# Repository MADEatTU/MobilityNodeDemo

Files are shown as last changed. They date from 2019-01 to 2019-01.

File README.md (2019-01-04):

# Mobility Node Demo
Proof of concept for CAN-bus connected mobility project modules.

This is a minimally viable circuit to prototype firmware and electrical designs communicating over CAN bus. Each board has one LED and three push buttons, allowing both targeted and global message passing to be tested. Boards are capable of daisy-chaining.

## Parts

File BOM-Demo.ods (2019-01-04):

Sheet: Timer
 | Description | Schematic Number | Manufacturer | Unit Price | Part # | Quantity | Total | Package | Link
1 | Arduino Nano | A1 |  | $4.62 |  | 1 | $4.62 |  | https://www.amazon.com/ELEGOO-Arduino-ATmega328P-Without-Compatible/dp/B0713XK923
2 | 1 uF Capacitor | C1 | Wurth | $0.15 | 710-885012208036 | 1 | $0.15 | SMD 1206 | https://www.mouser.com/ProductDetail/Wurth-Electronics/885012208036
3 | 0.1 uF Capacitor | C2, C5 | AVX | $0.10 | 581-12101C104KAZ4A | 2 | $0.20 | SMD 1210 | https://www.mouser.com/ProductDetail/AVX/12101C104KAZ4A
4 | 22 pF Capacitor | C3, C4 | Wurth | $0.11 | 710-885012008011 | 2 | $0.22 | SMD 1206 | https://www.mouser.com/ProductDetail/Wurth-Electronics/885012008011
5 | Schottky Diode | D1 | Rectron | $0.10 | 583-FM5817 | 1 | $0.10 | DO-214AC | https://www.mouser.com/ProductDetail/Rectron/FM5817-W
6 | Zener Diode 12V | D2 | ON | $0.14 | 863-BZX84C13LT1G | 1 | $0.14 | SOT-23 | https://www.mouser.com/ProductDetail/ON-Semiconductor/BZX84C13LT1G
7 | RJ14 Port | J1 | Molex | $0.78 | 538-95009-7641 | 2 | $1.56 |  | https://www.mouser.com/ProductDetail/Molex/95009-7641
 | 6.8 Ohm Resistor | R1 | Vishay | $0.10 | 71-CRCW1206-6.04-E3 | 1 | $0.10 | SMD 1206 | https://www.mouser.com/ProductDetail/Vishay/CRCW12066R04FKEA
8 | 100 Ohm Resistor | R2 | Ohmite | $0.10 | 588-AS12J1000ET | 1 | $0.10 | SMD 1206 | https://www.mouser.com/ProductDetail/Ohmite/AS12J1000ET
9 | 1k Ohm Resistor | R3-R6 | Vishay | $0.10 | 71-CRCW12061K00JNEAC | 4 | $0.40 | SMD 1206 | https://www.mouser.com/ProductDetail/Vishay/CRCW12061K00JNEAC
10 | 22k Ohm Resistor | R4, R5 | Bourns | $0.10 | 652-CR1206JW-223ELF | 1 | $0.10 | SMD 1206 | https://www.mouser.com/ProductDetail/Bourns/CR1206-JW-223ELF?qs=sGAEpiMZZMu61qfTUdNhG6LqqFhkr6pUaJfsmI3sDEY%3d
11 | Push Button Switch | SW1 | E-Switch | $0.17 | 612-TS-7.0-100 | 3 | $0.51 |  | https://www.mouser.com/ProductDetail/E-Switch/TS-70-100
12 | CAN Bus Transciever | U1 | Microchip | $1.06 | 579-MCP2551-I/SN | 1 | $1.06 | SOIC-8 | https://www.mouser.com/ProductDetail/Microchip-Technology/MCP2551-I-SN?qs=sGAEpiMZZMsUzhEcHltCudXjf0%252bf93ff
13 | CAN Bus Controller | U2 | Microchip | $1.88 | 579-MCP2515-I/SO | 1 | $1.88 | SOIC-18 | https://www.mouser.com/ProductDetail/Microchip-Technology/MCP2515-I-SO?qs=sGAEpiMZZMsUzhEcHltCuTyUJ%252bMSzD1r
14 | 8MHz Crystal Oscilator | Y1 | IQD | $0.23 | 449-LFXTAL030234REEL | 1 | $0.23 | HC49S | https://www.mouser.com/ProductDetail/IQD/LFXTAL030234Reel
15 | 15 position female header |  | Gravitech | $1.05 | 992-15FX1-254MM | 2 | $2.10 | SIP-15 | https://www.mouser.com/ProductDetail/Gravitech/15Fx1-254mm
 |  |  |  |  |  | Total: | $11.37

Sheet: ORDER THESE
Part # | Quantity | Units: | 5
710-885012208036 | 5
581-12101C104KAZ4A | 10
710-885012008011 | 10
583-FM5817 | 5
863-BZX84C13LT1G | 5
538-95009-7641 | 10
71-CRCW1206-6.04-E3 | 5
588-AS12J1000ET | 5
71-CRCW12061K00JNEAC | 20
652-CR1206JW-223ELF | 10
612-TS-7.0-100 | 15
579-MCP2551-I/SN | 4
579-MCP2515-I/SO | 4
449-LFXTAL030234REEL | 4
992-15FX1-254MM | 6

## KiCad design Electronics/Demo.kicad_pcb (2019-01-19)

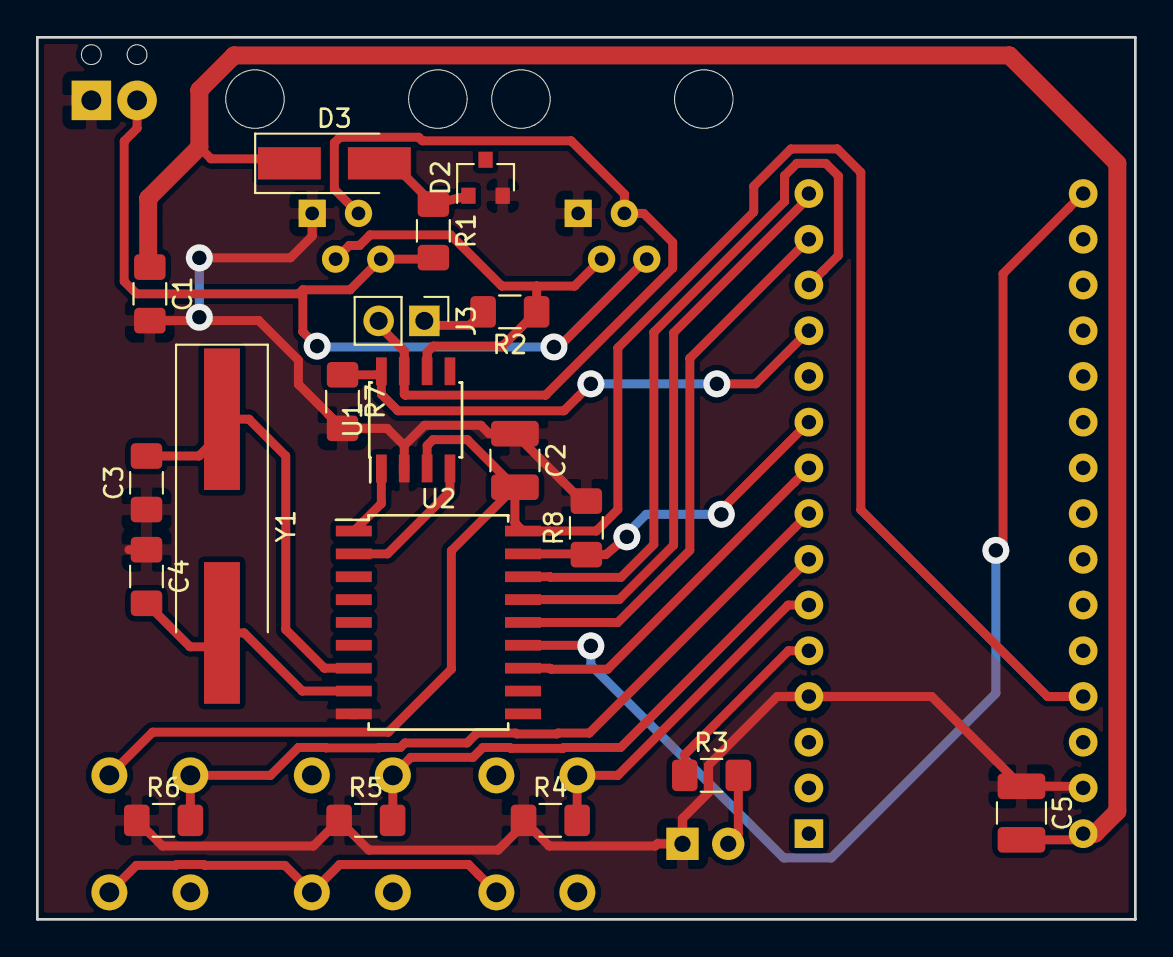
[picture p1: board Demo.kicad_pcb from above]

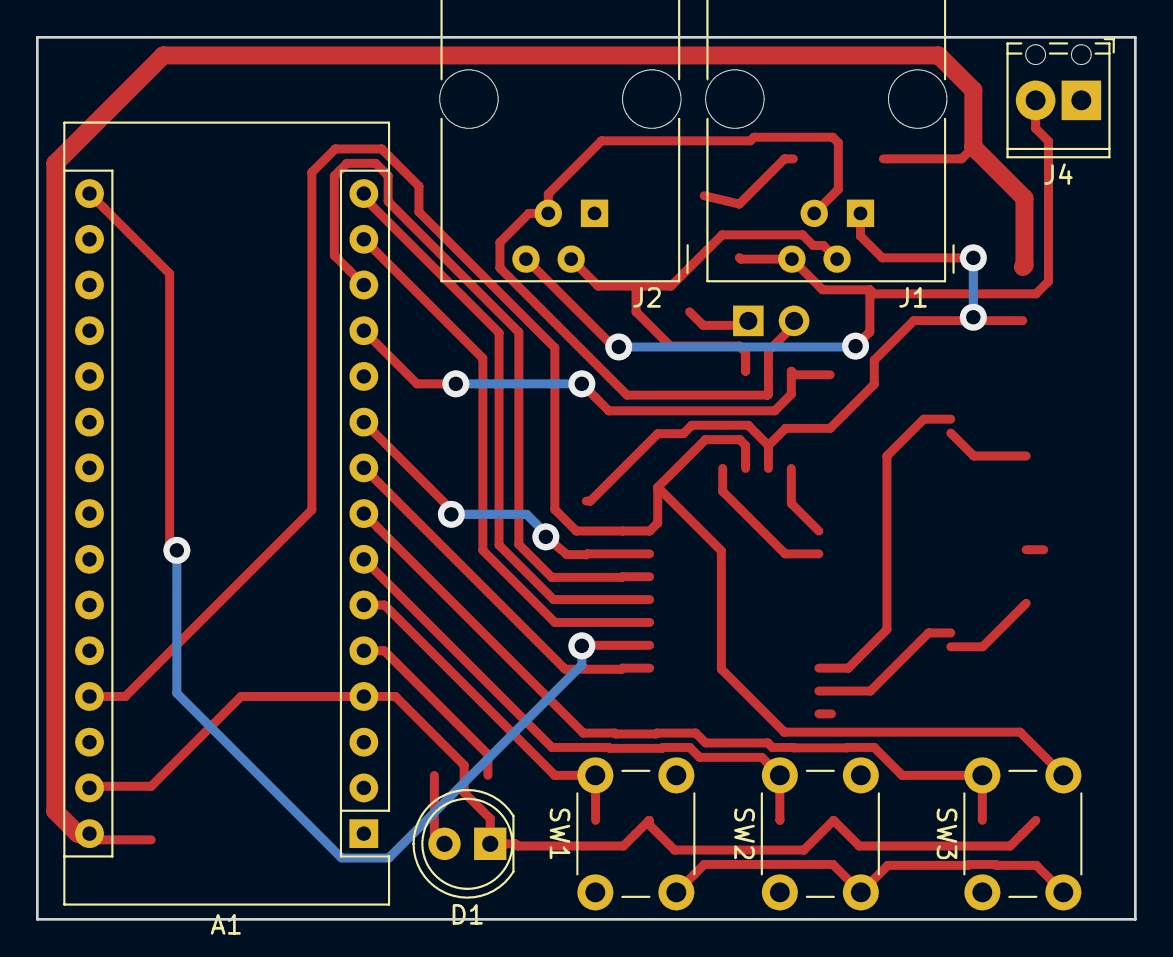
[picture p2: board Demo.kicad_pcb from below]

Board: 2 copper layers, 61.0 x 49.0 mm, 27 parts (8 on the bottom side), 24 nets.

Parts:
A1: Arduino_Nano_v3.x; Arduino_Nano
C1: 1uF; C_1206_3216Metric_Pad1.42x1.75mm_HandSolder
C2, C5: 0.1uF; C_1210_3225Metric_Pad1.42x2.65mm_HandSolder
C3, C4: 22pF; C_1206_3216Metric_Pad1.42x1.75mm_HandSolder
D1: LED; LED_D5.0mm
D2: 12V; SOT-23
D3: D_Schottky; D_SMA_Handsoldering
J1, J2: RJ10; RJ14
J3: Conn_01x02_Male; PinHeader_1x02_P2.54mm_Vertical
J4: PWR; TerminalBlock_Phoenix_MPT-0,5-2-2.54_1x02_P2.54mm_Horizontal
R1: 6.8; R_1206_3216Metric_Pad1.42x1.75mm_HandSolder
R2: 100; R_1206_3216Metric_Pad1.42x1.75mm_HandSolder
R3, R4, R5, R6: 1k; R_1206_3216Metric_Pad1.42x1.75mm_HandSolder
R7, R8: 22k; R_1206_3216Metric_Pad1.42x1.75mm_HandSolder
SW1, SW2, SW3: SW_Push; SW_PUSH_6mm_H4.3mm
U1: MCP2551-I-SN; SOIC-8_3.9x4.9mm_P1.27mm
U2: MCP2515-xSO; SOIC-18W_7.5x11.6mm_P1.27mm
Y1: 8MHz; Crystal_SMD_HC49-SD_HandSoldering

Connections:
+5V: A1.27, C2.2, SW1.2, SW2.2, SW3.2, U1.3, U2.18
+12V: A1.30, C1.1, C5.2, D3.1
/CANH: J1.3, J2.3, J3.2, U1.7
/CANL: J1.2, J2.2, R2.1, U1.6
/CAN_RST: A1.10, R8.1, U2.17
/CS: A1.13, U2.16
/LED: A1.5, R3.1
/RXD: U1.4, U2.2
/S1: A1.6, R4.2, SW1.1
/S2: A1.7, R5.2, SW2.1
/S3: A1.8, R6.2, SW3.1
/SCK: A1.16, U2.13
/SI: A1.14, U2.14
/SO: A1.15, U2.15
/TXD: U1.1, U2.1
/Vin: J1.4, J2.4, J4.2, R1.2
/XCDR_RST: A1.12, R7.1, U1.8
/int: A1.9, U2.12
GND: A1.4, A1.29, C1.2, C2.1, C3.1, C4.1, C5.1, D1.1, D2.2, J1.1, J2.1, J4.1, R4.1, R5.1, R6.1, R7.2, R8.2, U1.2, U2.9
unnamed: C3.2, U2.7, Y1.1
unnamed: C4.2, U2.8, Y1.2
unnamed: D1.2, R3.2
unnamed: D2.1, D3.2, R1.1
unnamed: J3.1, R2.2

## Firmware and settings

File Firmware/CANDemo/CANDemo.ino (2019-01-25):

#include <can.h>
#include <mcp2515.h>


void setup() {
  MCP2515 mcp2515(10);
  mcp2515.reset();
  mcp2515.setBitrate(CAN_125KBPS);
  mcp2515.setLoopbackMode();
  self.ID = 0;
}

void loop() {
  // put your main code here, to run repeatedly:
  // compare button state to previous
  // if button pressed == self.ID
    // set self.LED status == button status
  // else:
    // button_pressed(button_pressed, button_status)
  
  // on interupt: if can_id == self.ID:
    // set self.LED status == frame.data[0]
  
}

void button_pressed(int pin, bool button_status) {
  
  struct can_frame frame;
  frame.can_id = pin; // Target board ID corrosponding to button ID
  frame.can_dlc = 4;
  frame.data[0] = true; // Send status of button 
  frame.data[1] = 0xFF;
  frame.data[2] = 0xFF;
  frame.data[3] = 0xFF;
  
  /* send out the message to the bus and
  tell other devices this is a standard frame from 0x00. */
  mcp2515.sendMessage(&frame);
}

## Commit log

2019-01-04 Initial commit.
    [BOM-Demo.ods, Demo.kicad_pcb, Demo.sch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]
2019-01-06 Included power in screw terminal
2019-01-15 Updated footprints and routing.
    [Demo.kicad_pcb, Demo.sch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]
2019-01-18 Duplicate work.
    [Demo.kicad_pcb, Demo.sch]
2019-01-19 Corrected footprint and tuned traces.
    [Demo.kicad_pcb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]
